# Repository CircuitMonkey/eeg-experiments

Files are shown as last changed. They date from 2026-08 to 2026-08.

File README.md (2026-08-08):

# eeg-experiments
Experiments in EEG hardware and software.

<h2>EEG Single Channel CHiPz Module</h2>
The single channel module for EEG input is designed as a SMT CHiPz module for integration into larger designs.  It features an optimized and lower cost version of the [Upside Down Labs BioAmp EXG Pill](https://github.com/upsidedownlabs/bioAmp-exg-pill).  For our design, we removed some configuration options such that the user would opt to simply modify the components on the board for the specific purpose such as EEG/EOG/EKG/etc.

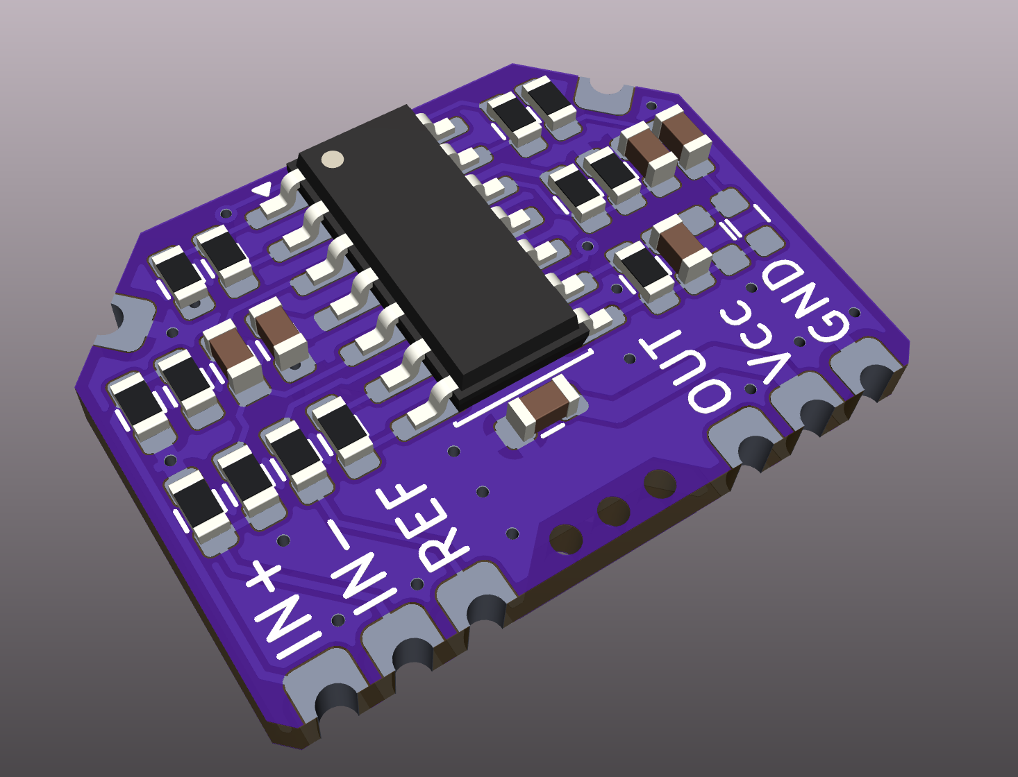
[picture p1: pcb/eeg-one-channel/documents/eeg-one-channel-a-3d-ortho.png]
EEG One Channel. Rev.A Ortho View
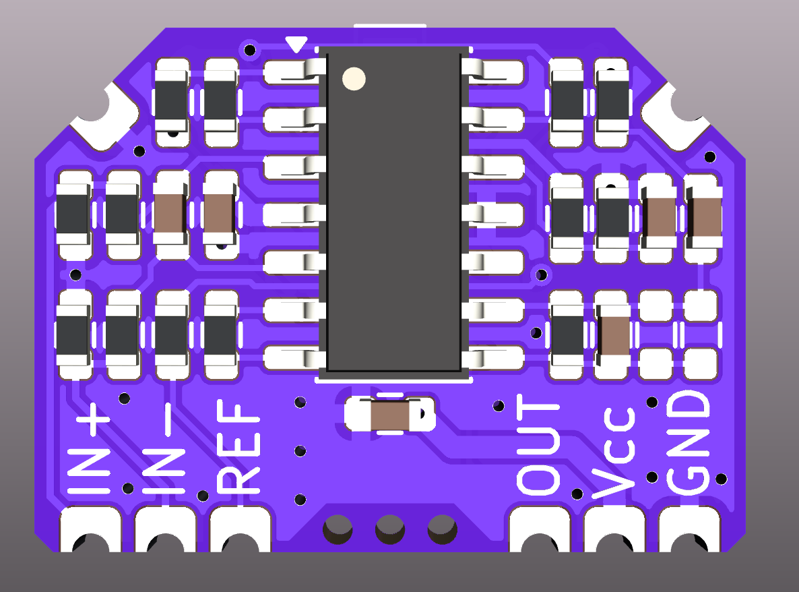
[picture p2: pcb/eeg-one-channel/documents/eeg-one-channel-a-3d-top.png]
EEG One Channel. Rev.A Top View
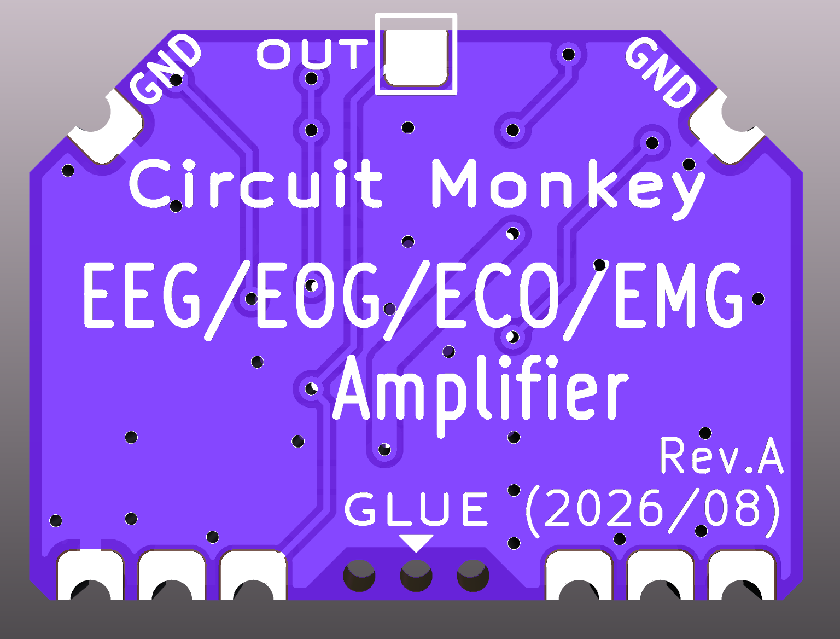
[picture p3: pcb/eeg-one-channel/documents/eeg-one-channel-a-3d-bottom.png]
EEG One Channel. Rev.A Bottom View


<h2>Example/Test Carrier for EEG Single Channel CHiPz Module</h2>
We made a simple carrier PCB for the single channel EEG sensor CHiPz module so that we could test it as well as its easy use in a prototyping environment.  We also made a KiCAD symbol and footprint for the module so that you can integrate the module into your own PCB designs. The CHiPz KiCAD symbol and footprint library is located in separate [ GIT Hub repo ](https://github.com/circuitmonkey/kicad-library). That repo also includes many KiCAD components that we have created or tuned to be superior to the standard KiCAD components.

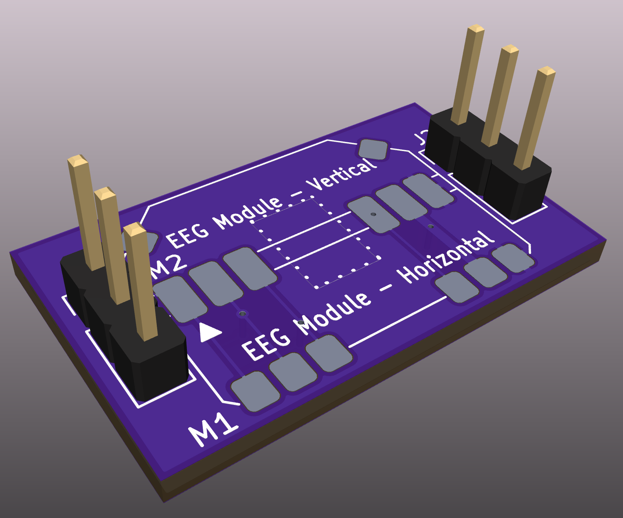
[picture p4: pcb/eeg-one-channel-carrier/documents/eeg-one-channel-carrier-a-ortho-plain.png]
Carrier PCB for the EEG One Channel. Rev.A -- Ortho View - No module installed
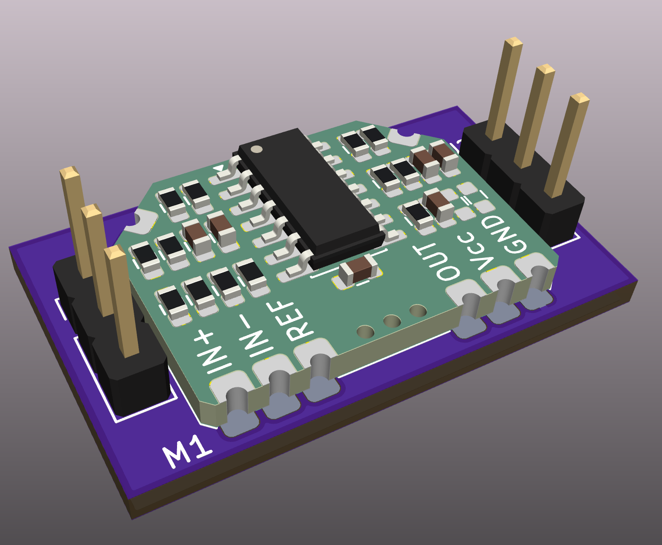
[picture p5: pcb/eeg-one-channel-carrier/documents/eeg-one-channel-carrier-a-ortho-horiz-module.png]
Carrier PCB for the EEG One Channel. Rev.A -- Horizontal Module Installed
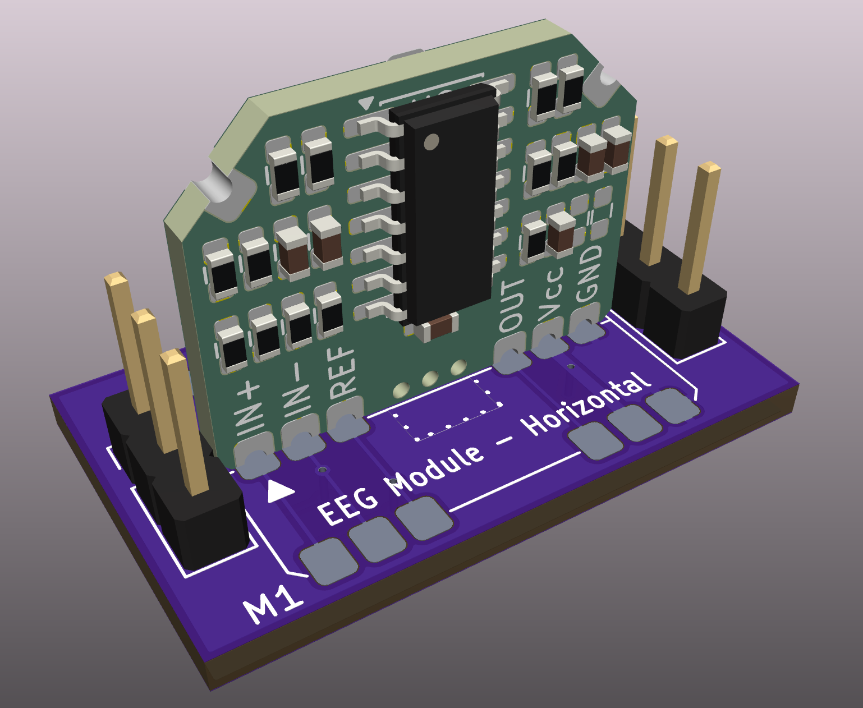
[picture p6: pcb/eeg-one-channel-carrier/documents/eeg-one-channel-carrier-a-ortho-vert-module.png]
Carrier PCB for the EEG One Channel. Rev.A -- Vert Module Installed
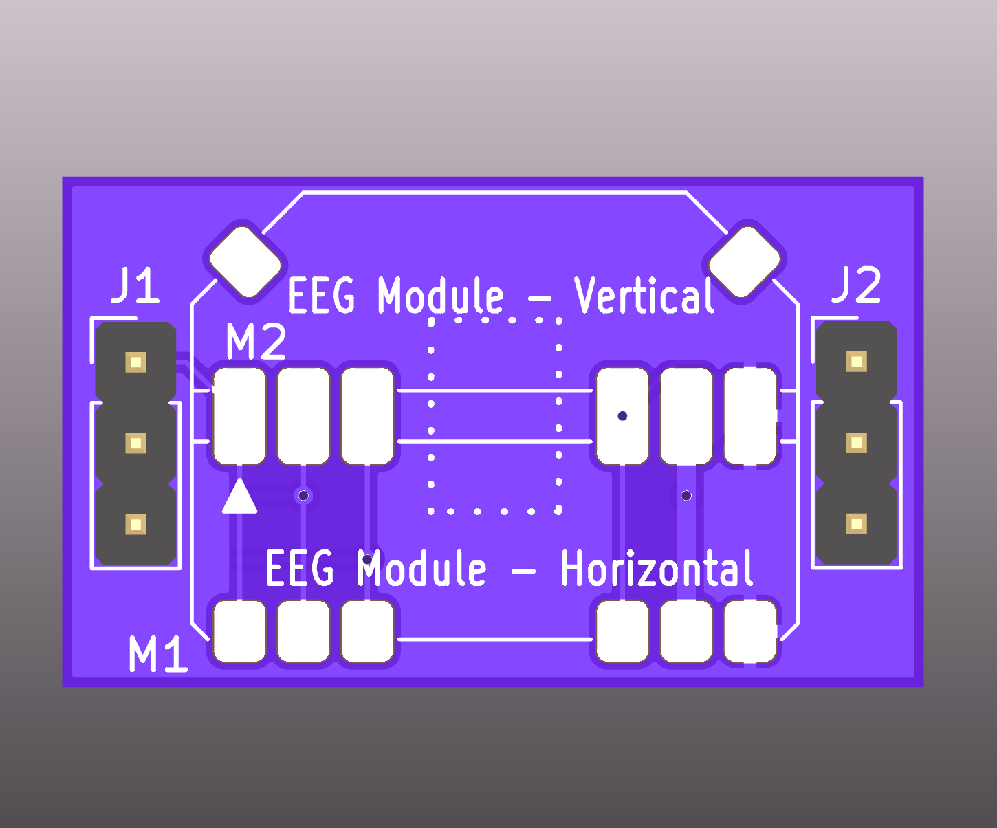
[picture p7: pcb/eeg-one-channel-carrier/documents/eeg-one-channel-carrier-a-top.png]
Carrier PCB for the EEG One Channel. Rev.A -- Top View
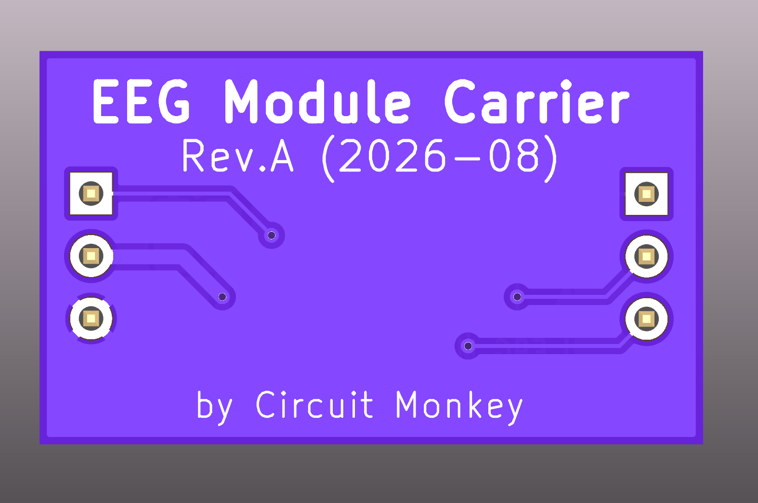
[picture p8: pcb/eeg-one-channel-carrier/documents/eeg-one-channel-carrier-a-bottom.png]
Carrier PCB for the EEG One Channel. Rev.A -- Bottom View


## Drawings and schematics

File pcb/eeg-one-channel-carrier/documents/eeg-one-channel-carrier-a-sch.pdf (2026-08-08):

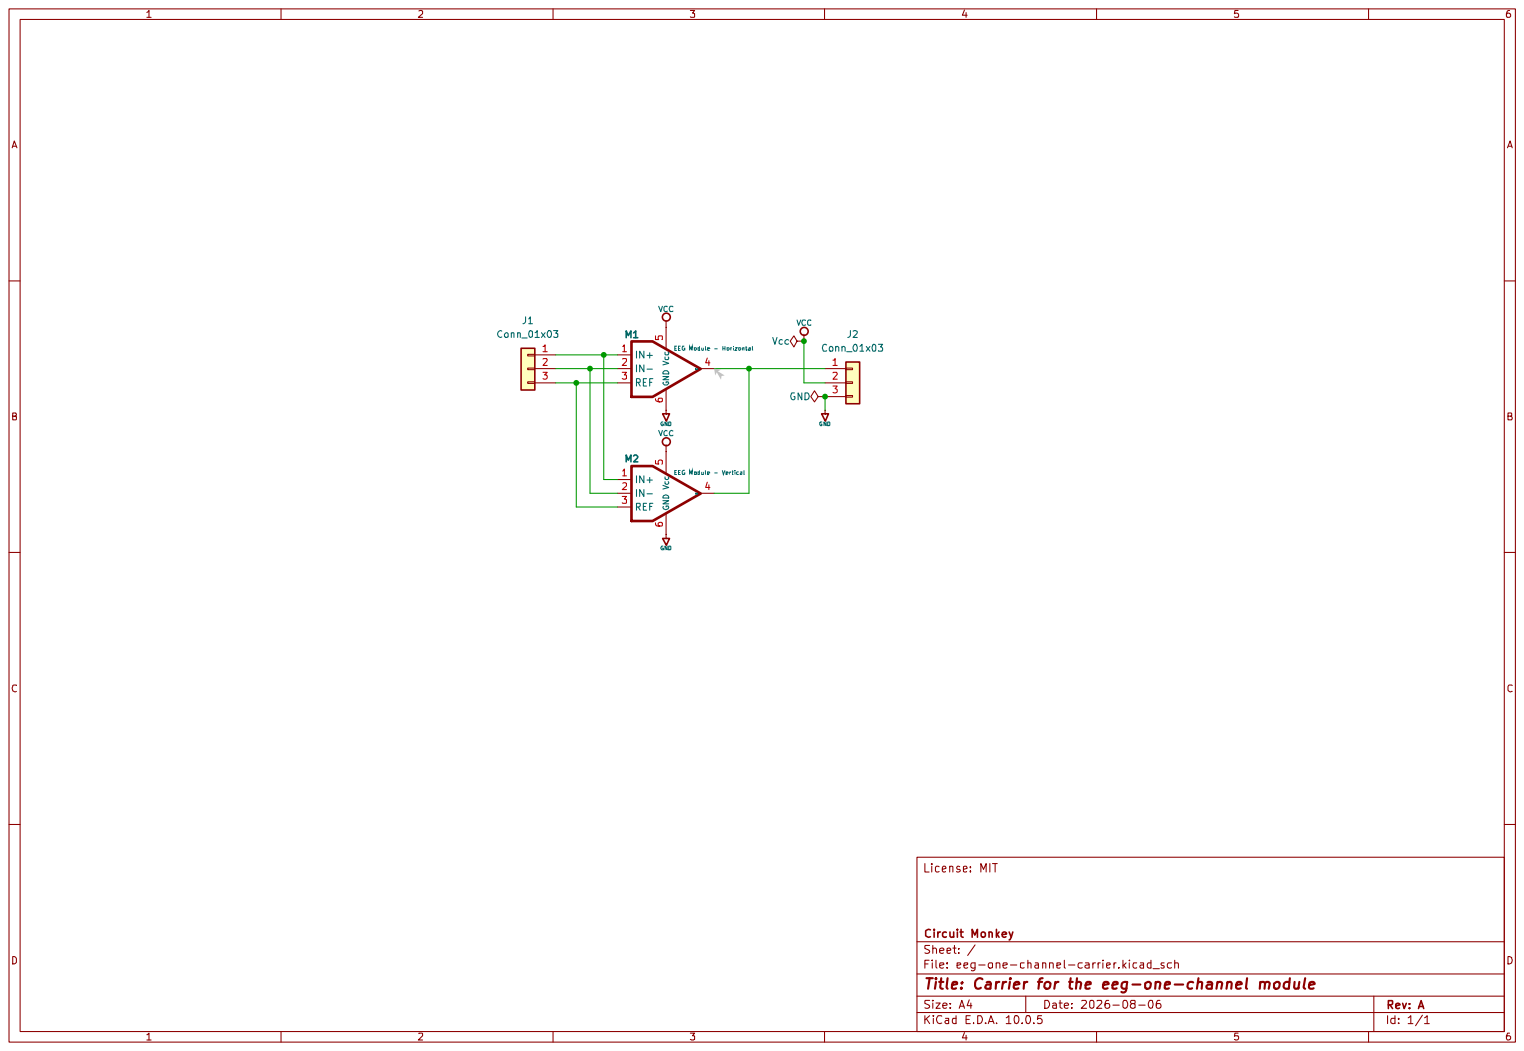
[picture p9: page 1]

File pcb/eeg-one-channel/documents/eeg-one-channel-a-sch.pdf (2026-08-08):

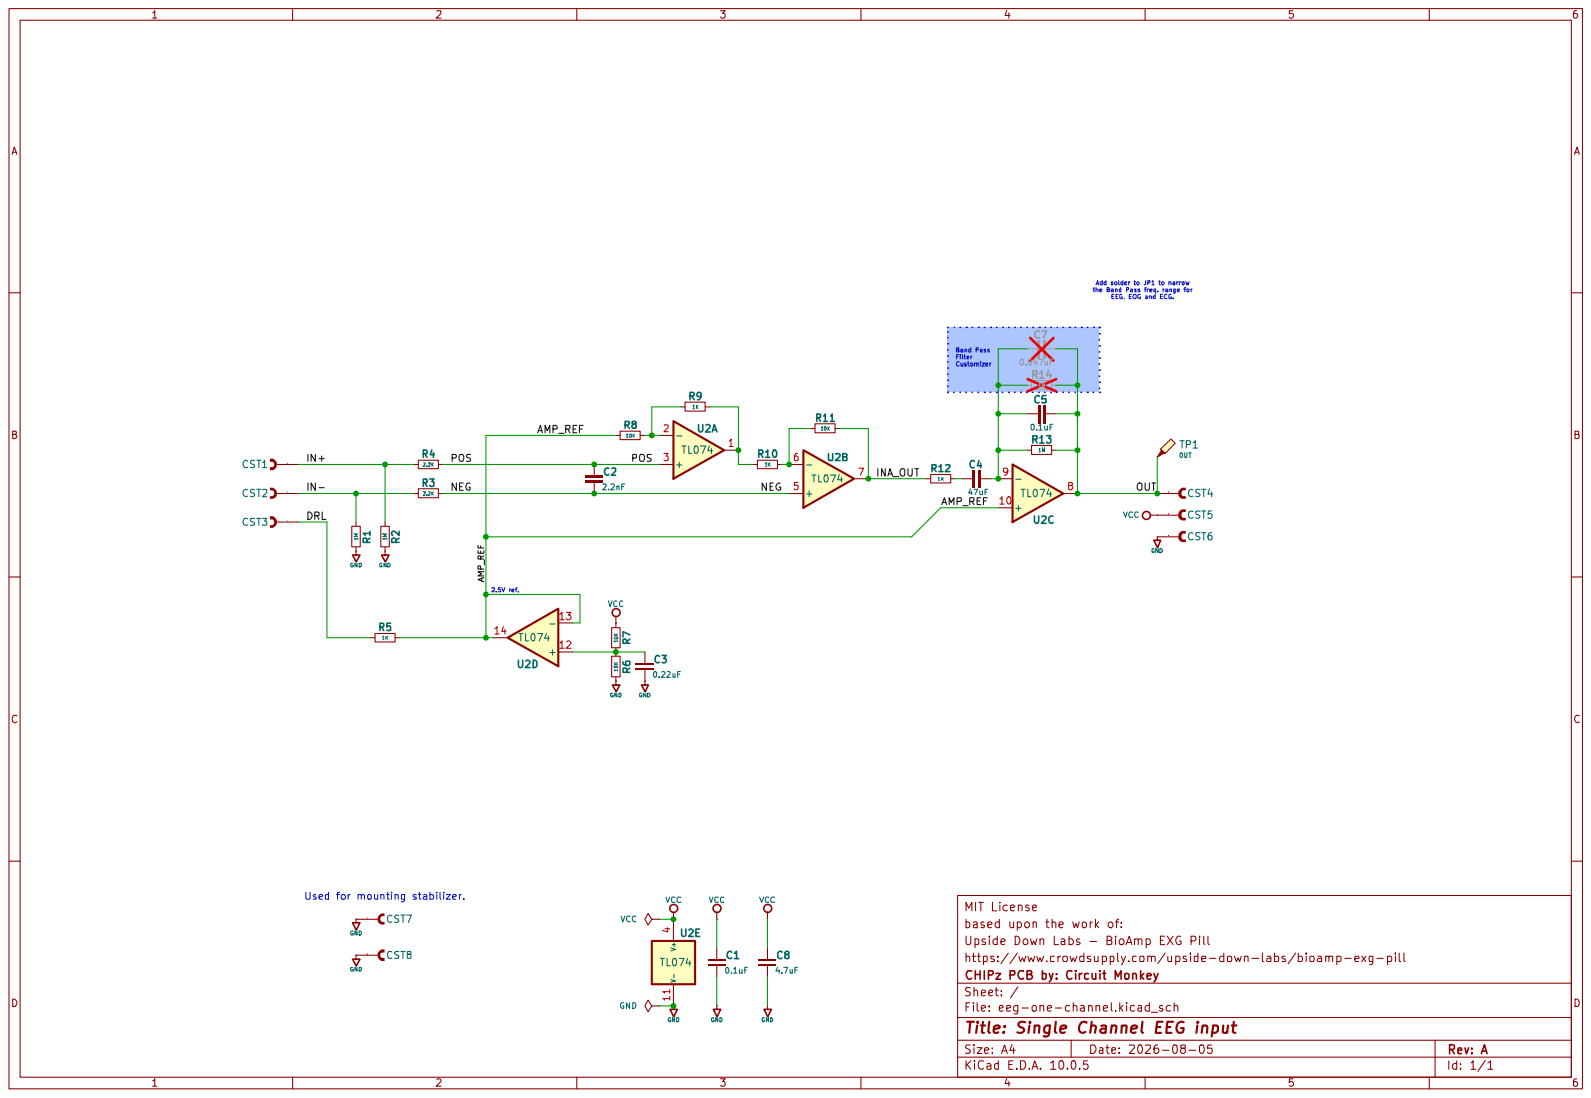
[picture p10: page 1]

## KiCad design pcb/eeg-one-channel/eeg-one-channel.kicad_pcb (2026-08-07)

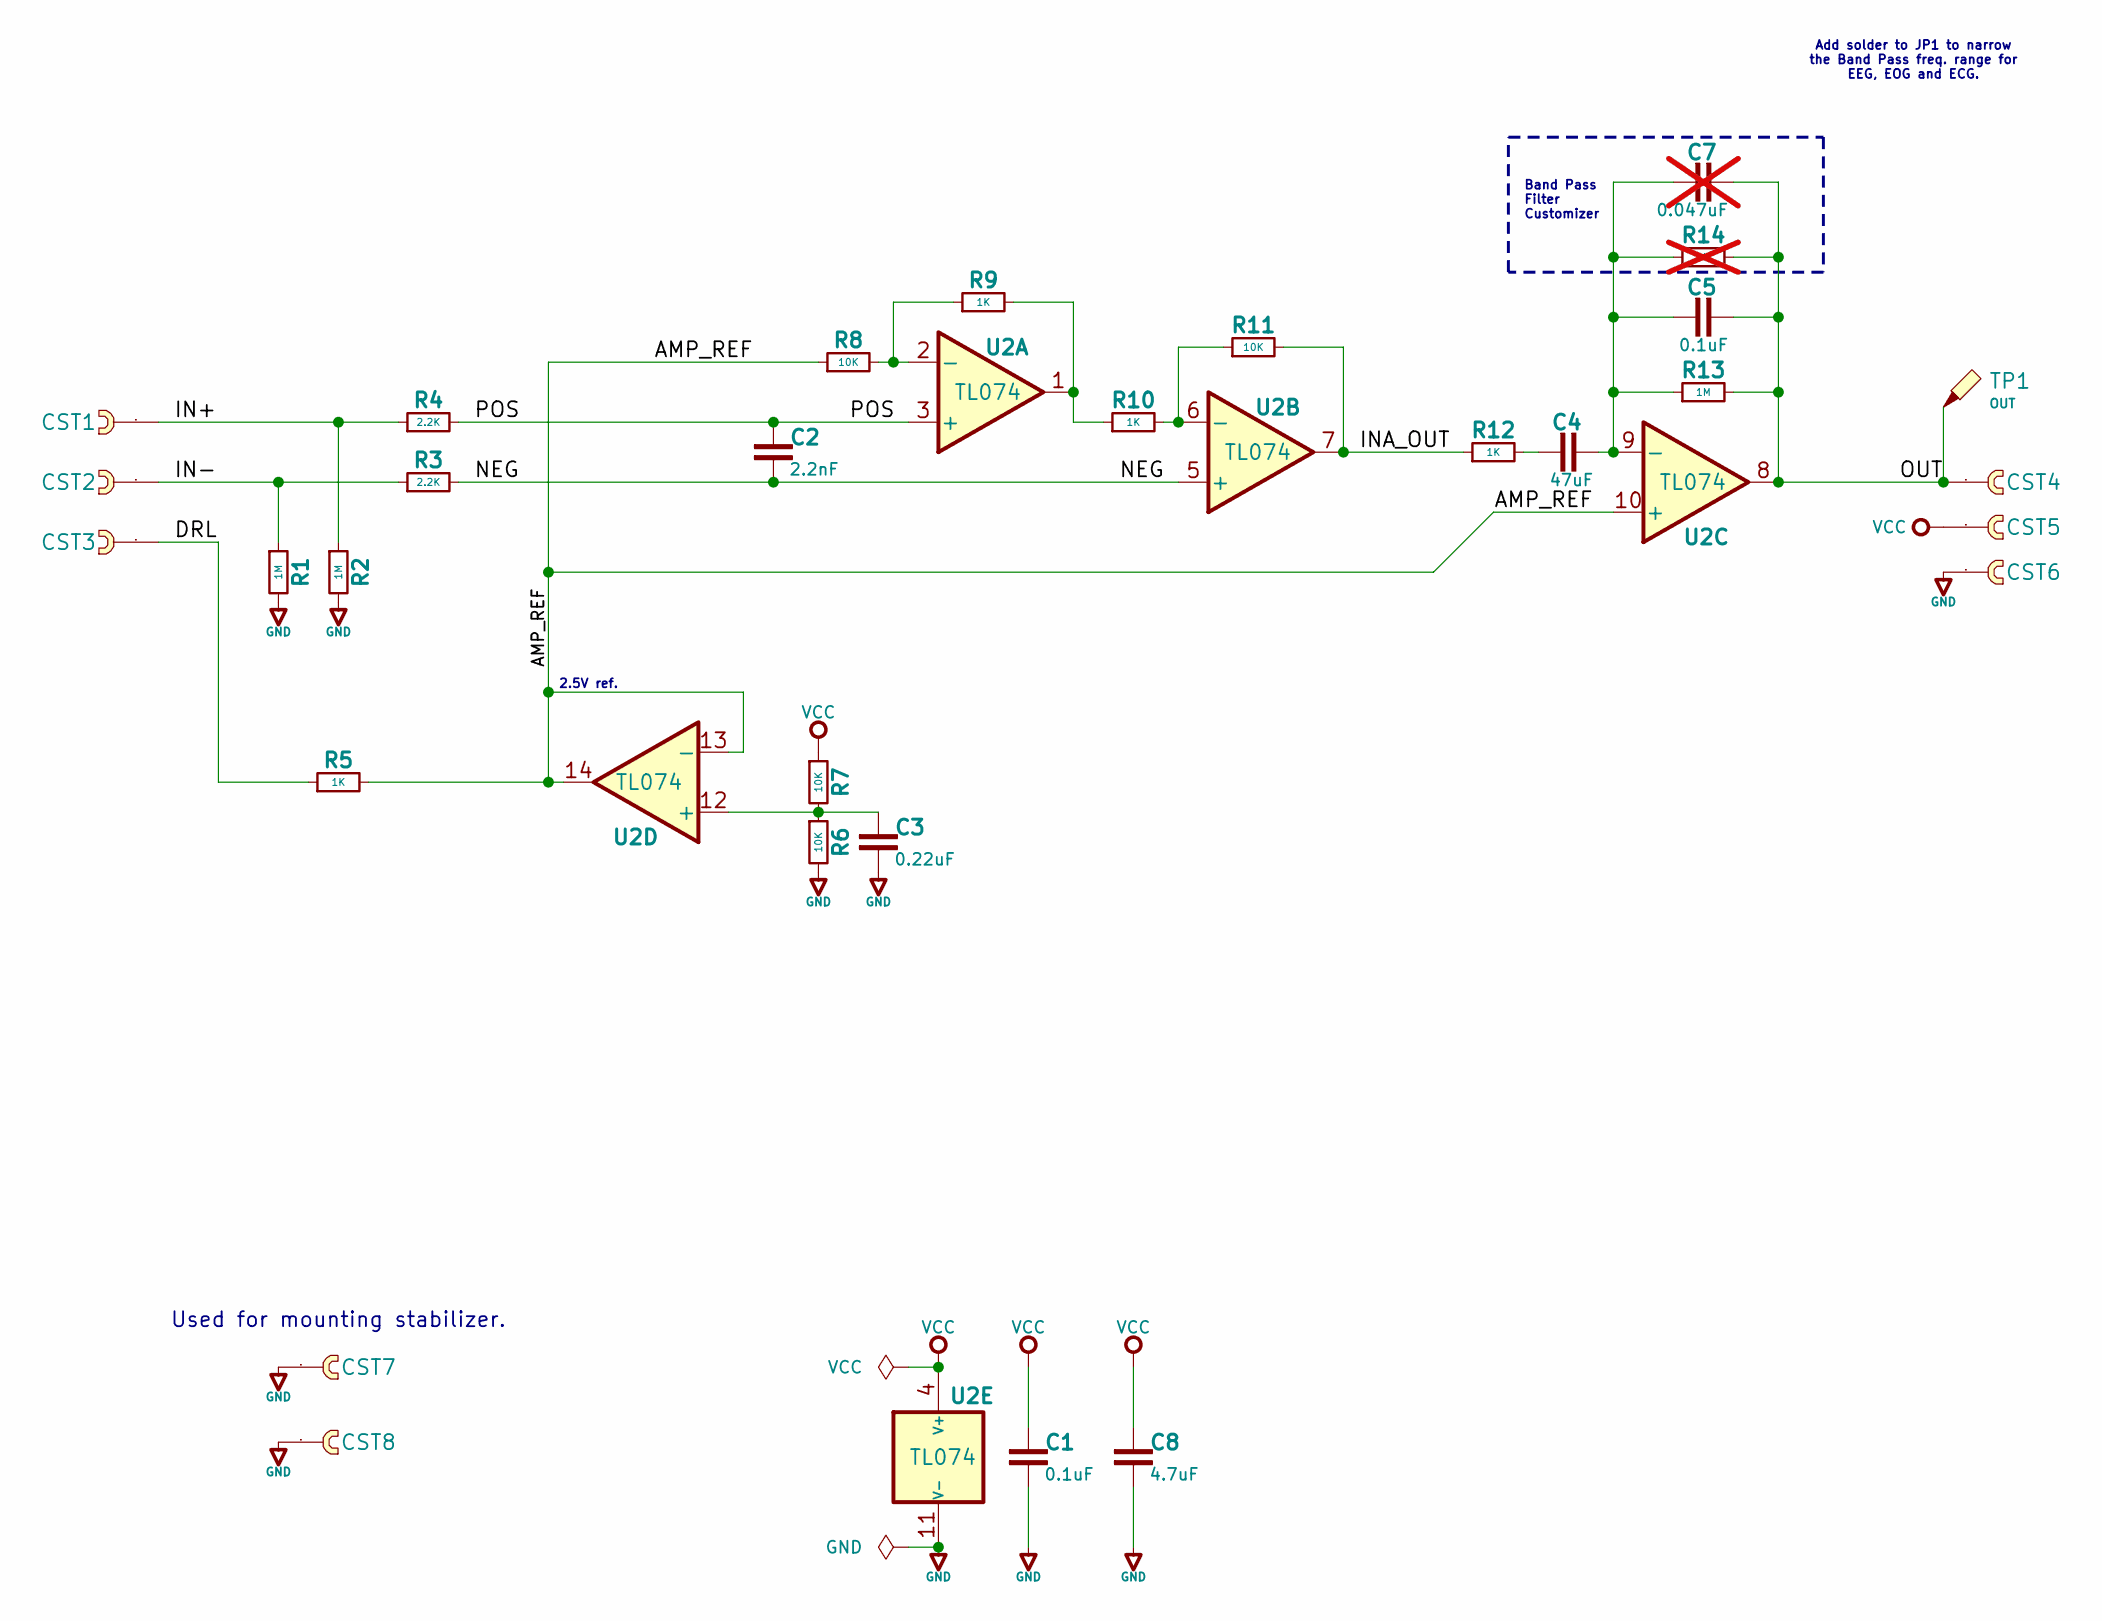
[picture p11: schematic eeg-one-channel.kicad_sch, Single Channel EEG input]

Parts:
C1, C5: 0.1uF; C_0603_1608Metric
C2: 2.2nF; C_0603_1608Metric
C3: 0.22uF; C_0603_1608Metric
C4: 47uF; C_0603_1608Metric
C7: 0.047uF; C_0603_1608Metric; not fitted
C8: 4.7uF; C_0603_1608Metric
CST1: IN+; cast-2.0-01P
CST2: IN-; cast-2.0-01P
CST3: REF; cast-2.0-01P
CST4: OUT; cast-2.0-01P
CST5: Vcc; cast-2.0-01P
CST6, CST7, CST8: GND; cast-2.0-01P
R1, R2, R13: 1M; R_0603_1608Metric
R3, R4: 2.2K; R_0603_1608Metric
R5, R9, R10, R12: 1K; R_0603_1608Metric
R6, R7, R8, R11: 10K; R_0603_1608Metric
R14: 1M; R_0603_1608Metric; not fitted
TP1: OUT; TestPoint_Pad_1.5x1.5mm
U2: TL074; SO-14_3.9x8.65mm_P1.27mm; MPN TL074HIDR

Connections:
/AMP_REF: R5.2, R8.1, U2.10 (+), U2.13 (-), U2.14
/DRL: CST3.1, R5.1
/IN+: CST1.1, R2.1, R4.1
/IN-: CST2.1, R1.1, R3.1
/INA_OUT: R11.2, R12.1, U2.7
/NEG: C2.2, R3.2, U2.5 (+)
/OUT: C5.2, C7.2, CST4.1, R13.2, R14.2, TP1.1 (1_1), U2.8
/POS: C2.1, R4.2, U2.3 (+)
GND: C1.2, C3.2, C8.2, CST6.1, CST7.1, CST8.1, R1.2, R2.2, R6.2, U2.11 (V-)
unnamed: C4.1, R12.2
unnamed: R9.2, R10.1, U2.1
unnamed: R8.2, R9.1, U2.2 (-)
unnamed: R10.2, R11.1, U2.6 (-)
unnamed: C4.2, C5.1, C7.1, R13.1, R14.1, U2.9 (-)
unnamed: C3.1, R6.1, R7.2, U2.12 (+)
VCC: C1.1, C8.1, CST5.1, R7.1, U2.4 (V+)

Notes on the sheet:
Add solder to JP1 to narrow the Band Pass freq. range for EEG, EOG and ECG.
Used for mounting stabilizer.
Band Pass Filter Customizer
2.5V ref.

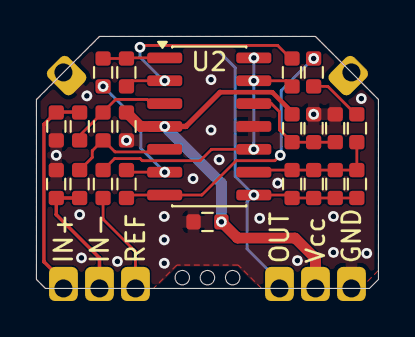
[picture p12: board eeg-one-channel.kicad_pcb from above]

Board: 2 copper layers, 19.0 x 14.0 mm, 31 parts (1 on the bottom side), 16 nets.

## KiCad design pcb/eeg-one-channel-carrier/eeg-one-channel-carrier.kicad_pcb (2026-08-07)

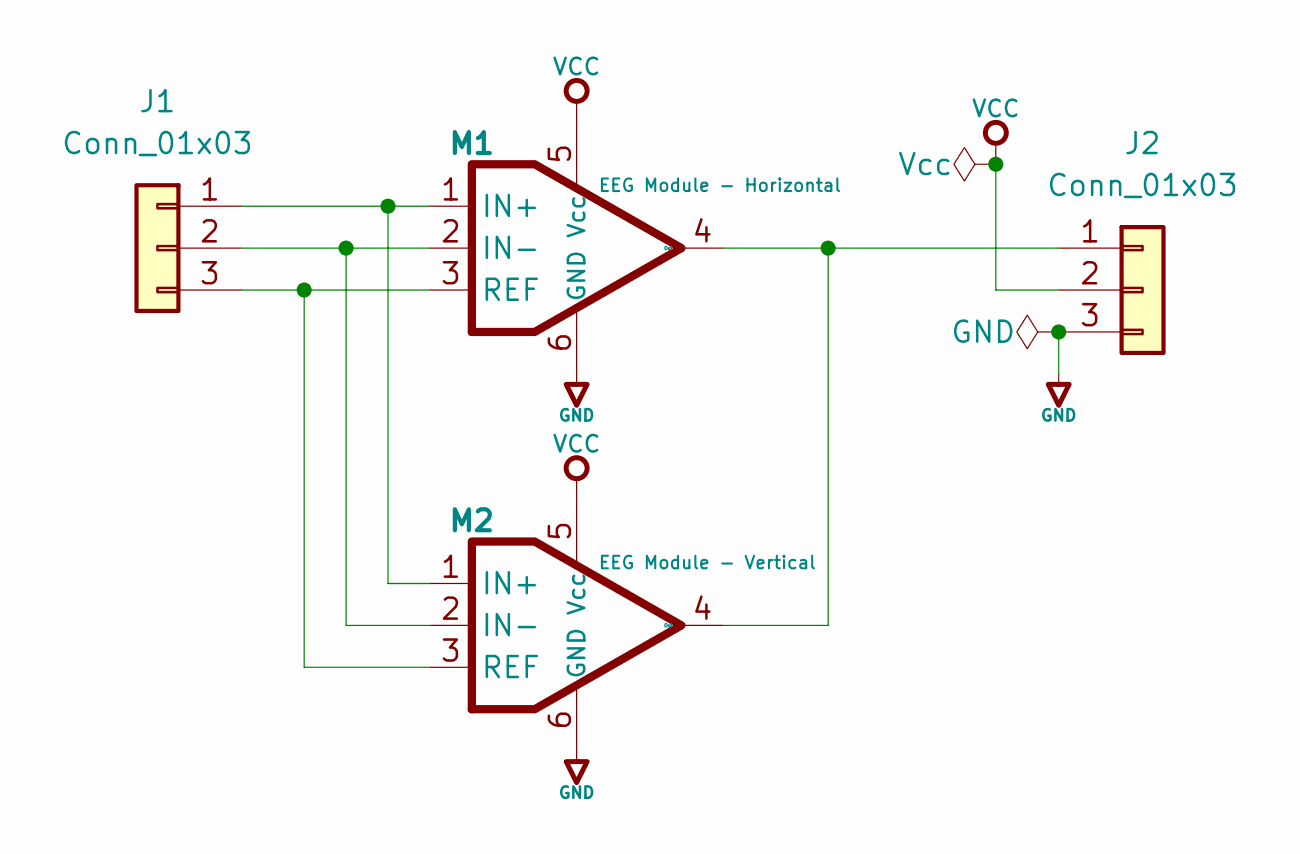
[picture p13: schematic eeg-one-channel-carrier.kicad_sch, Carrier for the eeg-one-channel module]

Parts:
J1, J2: Conn_01x03; PinHeader_1x03_P2.54mm_Vertical
M1: EEG Module - Horizontal; eeg-one-channel
M2: EEG Module - Vertical; eeg-one-channel_vert

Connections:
GND: J2.3, M1.6 (GND), M2.6 (GND)
unnamed: J1.1, M1.1 (IN+), M2.1 (IN+)
unnamed: J1.2, M1.2 (IN-), M2.2 (IN-)
unnamed: J1.3, M1.3 (REF), M2.3 (REF)
unnamed: J2.1, M1.4 (Out), M2.4 (Out)
VCC: J2.2, M1.5 (Vcc), M2.5 (Vcc)

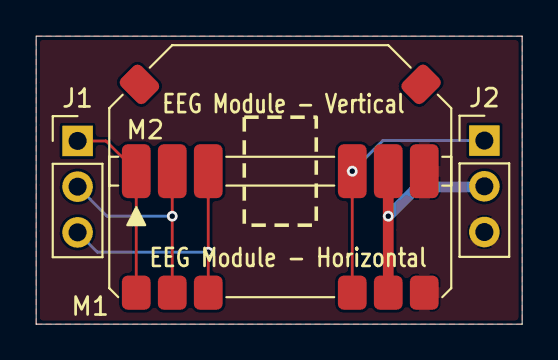
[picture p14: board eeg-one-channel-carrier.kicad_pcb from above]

Board: 2 copper layers, 27.0 x 16.0 mm, 4 parts (0 on the bottom side), 6 nets.

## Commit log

2026-08-07 Create PCB and Carrier PCB
    [eeg-one-channel-carrier.kicad_pcb, eeg-one-channel-carrier.kicad_sch, eeg-one-channel.kicad_pcb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]
2026-08-08 Add schematic for EEG module
2026-08-08 Add carrier schematic
2026-08-08 Add PCB images and update README

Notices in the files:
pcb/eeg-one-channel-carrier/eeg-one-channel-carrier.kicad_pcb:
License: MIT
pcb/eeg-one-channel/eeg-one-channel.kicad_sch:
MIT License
